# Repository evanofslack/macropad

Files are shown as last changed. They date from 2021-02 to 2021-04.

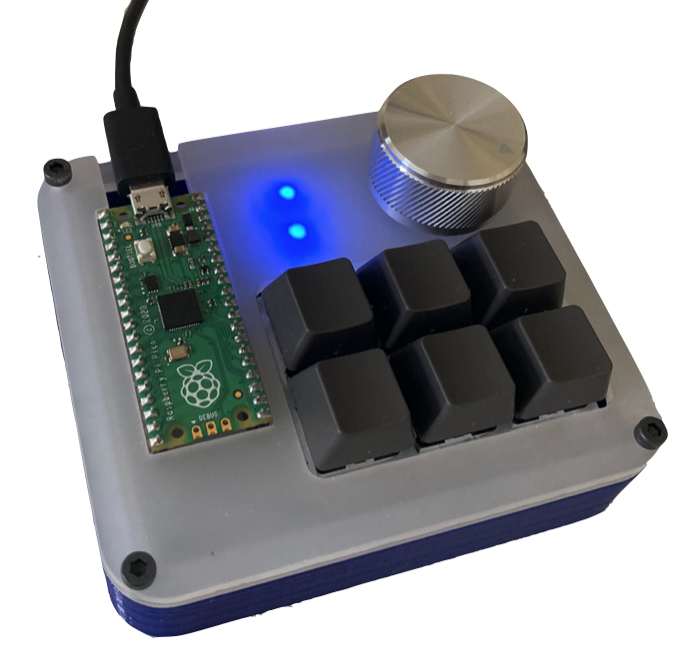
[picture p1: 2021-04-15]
Images/Final_Build.png

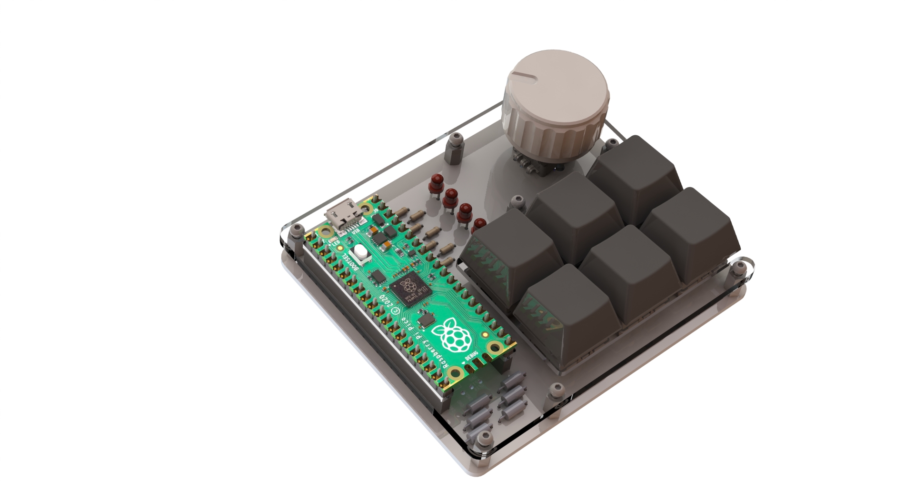
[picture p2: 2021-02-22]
Images/SlackPadv1.3 Render 1.JPG

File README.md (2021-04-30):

# MacroPad

Macropad utilizing the Raspberry Pi Pico. 3 layers of functionality, 6 switches, and 1 rotary encoder switch. Implements CircuitPython HID libraries and Adafruit matrix keypad library. Custom PCB designed in KiCAD (Gerbers can be found in the folder). Custom case designed in SolidWorks featuring a lasercut acrylic plates and a 3D printed base. 



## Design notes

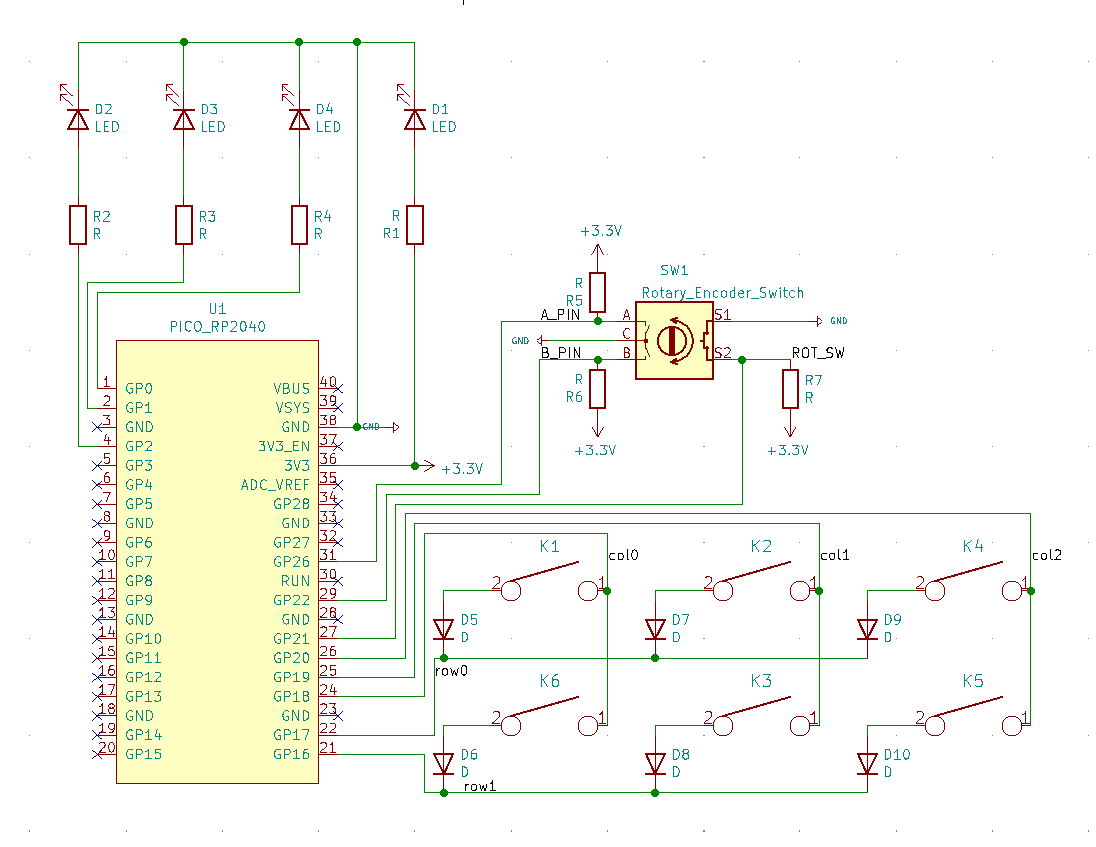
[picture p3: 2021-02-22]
Images/Schematic_v3.PNG

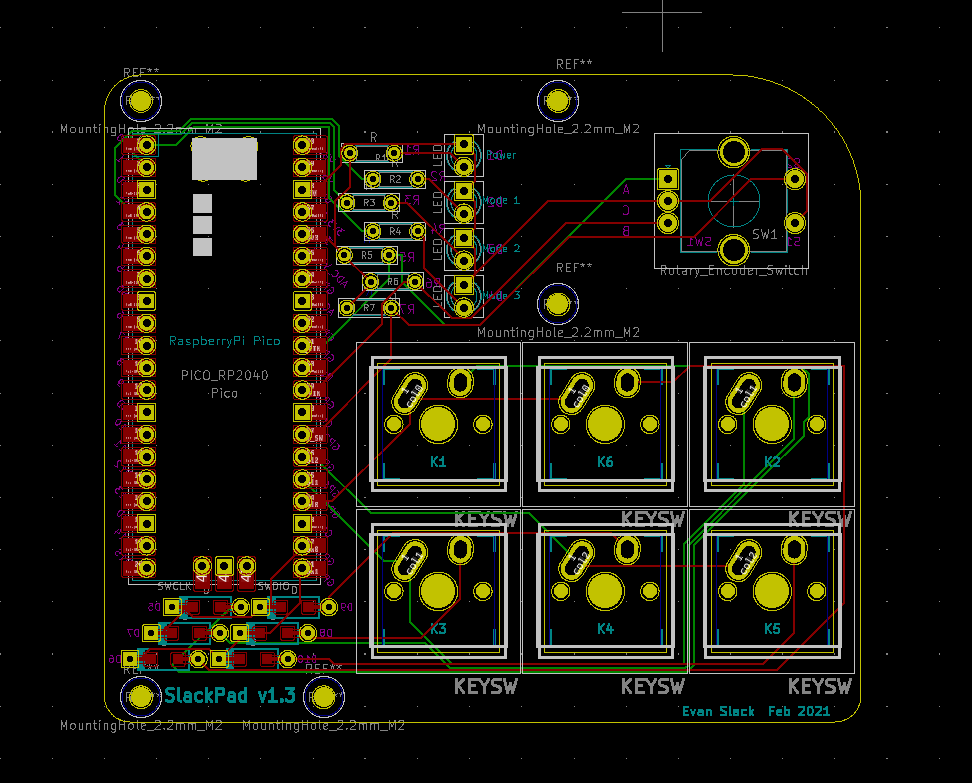
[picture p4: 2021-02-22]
Images/PCB_v3.PNG

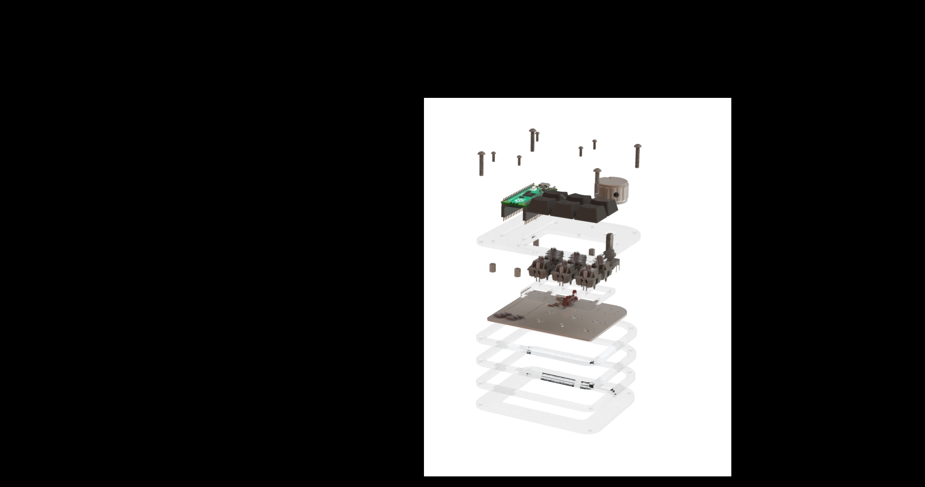
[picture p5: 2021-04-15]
Images/Untitled.JPG

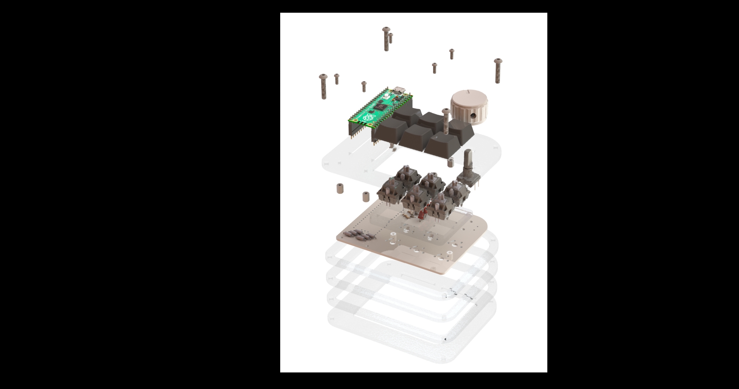
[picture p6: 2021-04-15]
Images/WEhite.JPG

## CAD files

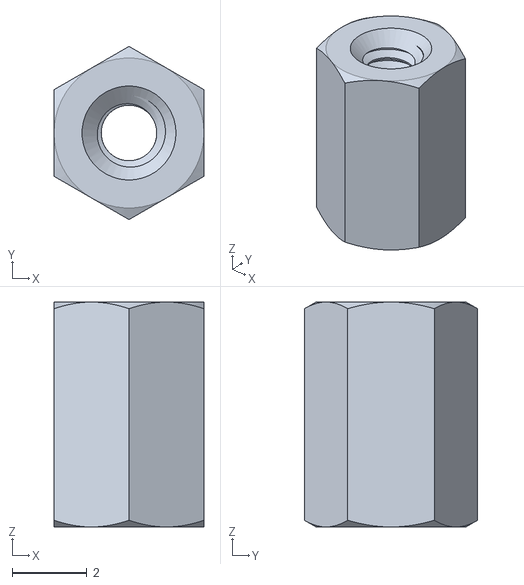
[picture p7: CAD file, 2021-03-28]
CAD/02_OTS/M2 Standoff.STL
4.00 x 4.62 x 6.00

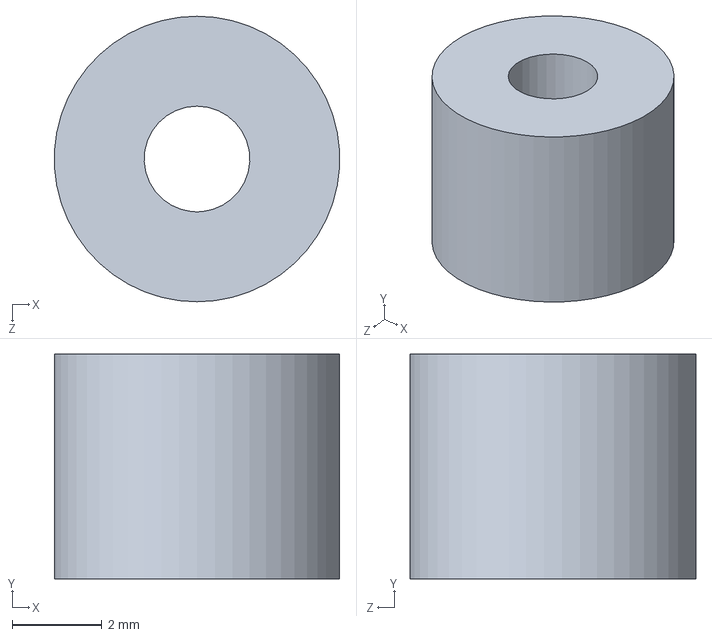
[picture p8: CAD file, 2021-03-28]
CAD/03_Acrylic/Custom Standoff.SLDPRT
6.34 x 5.00 x 6.35 mm

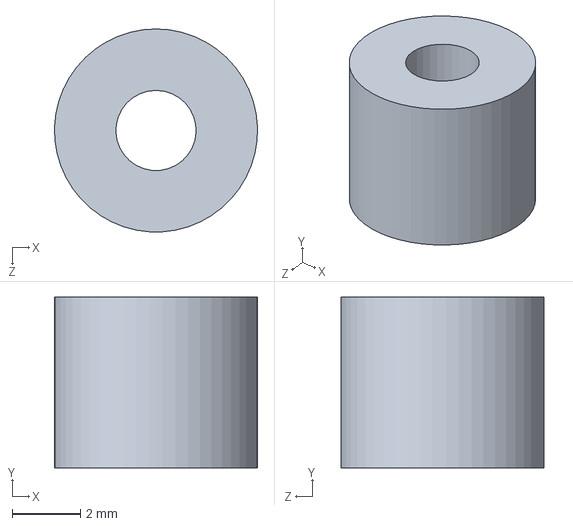
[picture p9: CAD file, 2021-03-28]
CAD/04_3DPrint/Custom Standoff.SLDPRT
5.95 x 5.00 x 5.95 mm

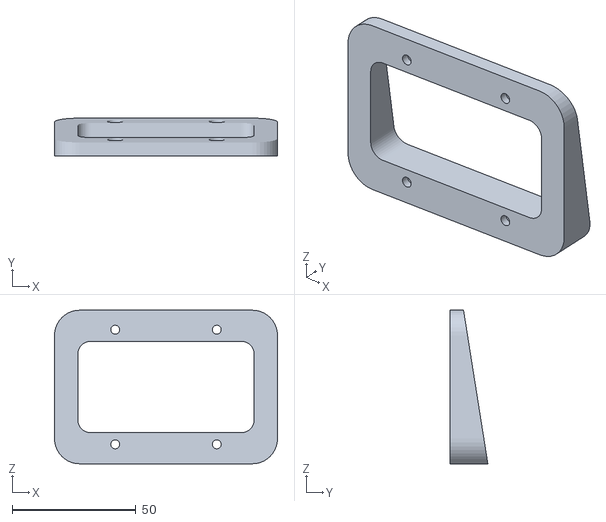
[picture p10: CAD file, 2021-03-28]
CAD/04_3DPrint/STL/Case Foot.STL
90.0 x 15.2 x 62.0

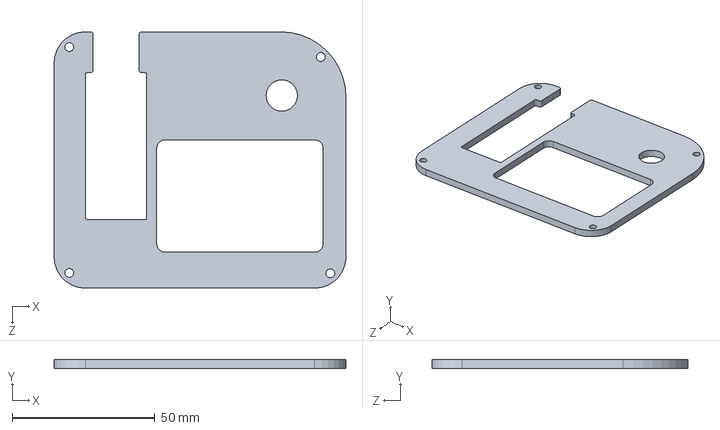
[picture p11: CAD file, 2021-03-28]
CAD/03_Acrylic/Acrylic Top Plate.SLDPRT
102.3 x 3.05 x 89.8 mm

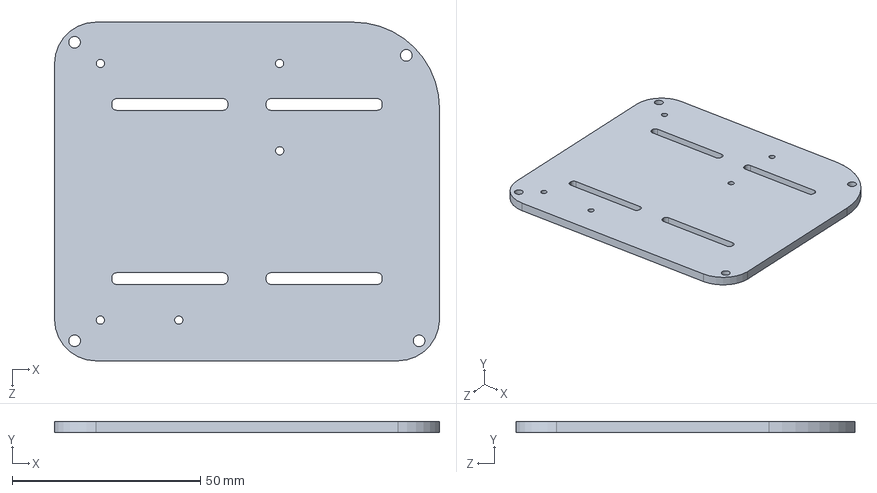
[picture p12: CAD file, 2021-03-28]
CAD/03_Acrylic/Bottom Case Plate NEW.SLDPRT
102.3 x 3.05 x 90.0 mm

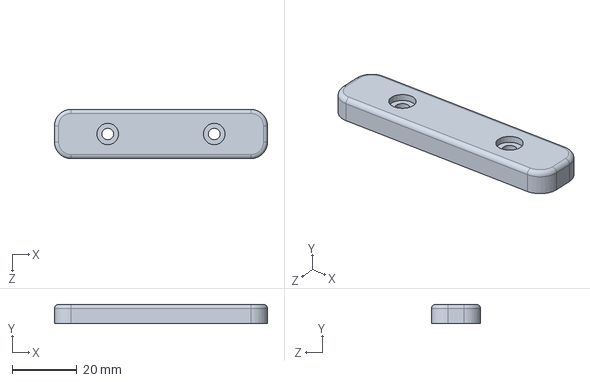
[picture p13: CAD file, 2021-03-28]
CAD/04_3DPrint/Case Foot Front.SLDPRT
66.0 x 6.00 x 15.2 mm

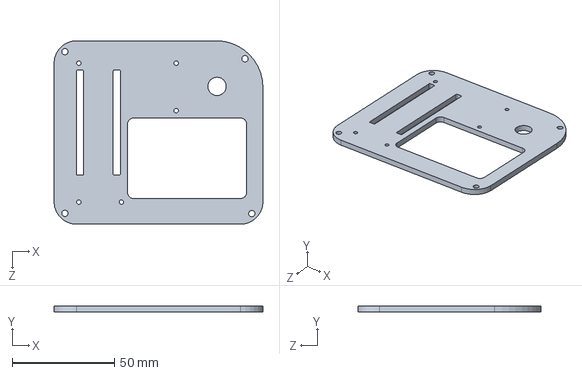
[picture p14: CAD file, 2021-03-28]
CAD/03_Acrylic/Top Case Plate.SLDPRT
102.3 x 3.05 x 89.8 mm

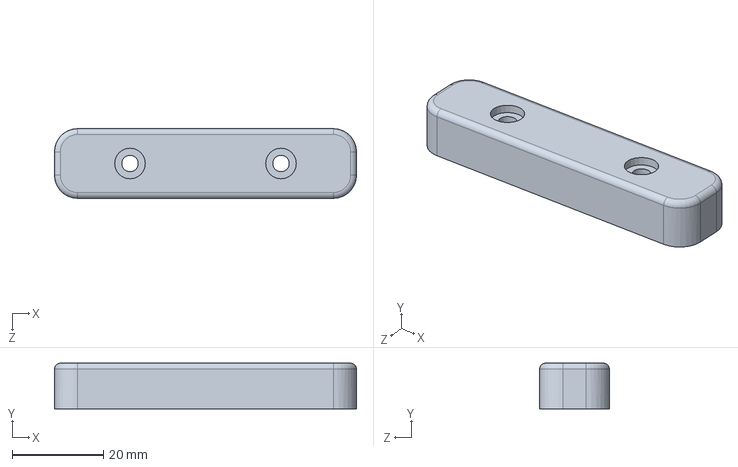
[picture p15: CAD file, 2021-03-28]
CAD/04_3DPrint/Case Foot Back.SLDPRT
66.0 x 10.0 x 15.2 mm

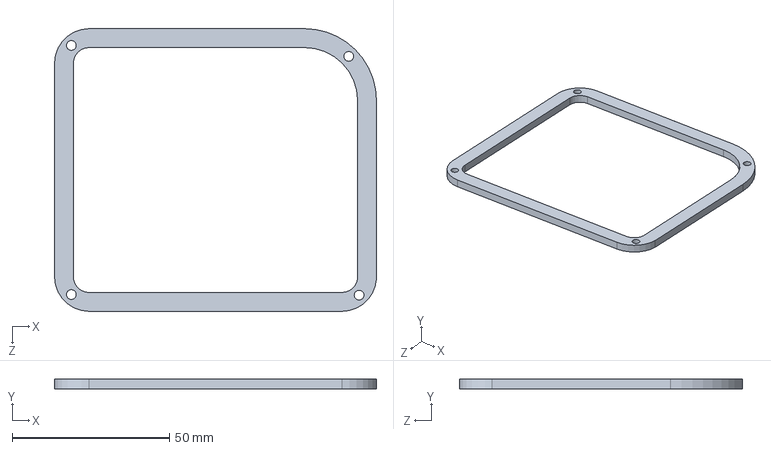
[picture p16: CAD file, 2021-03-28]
CAD/03_Acrylic/Middle Case Plate.SLDPRT
102.3 x 3.10 x 89.8 mm

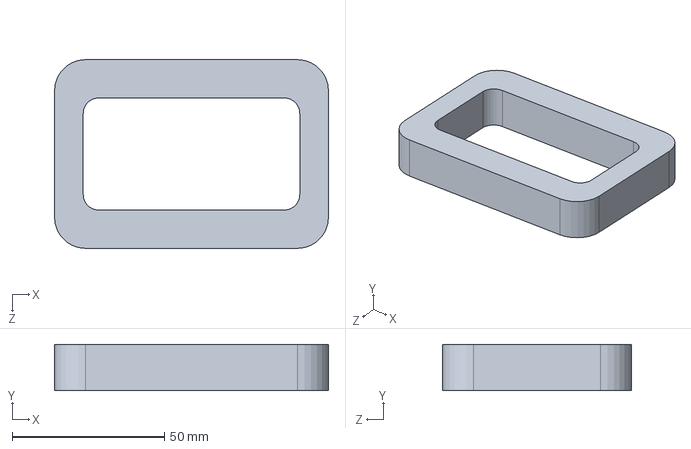
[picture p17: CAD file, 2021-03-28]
CAD/04_3DPrint/Case Base.SLDPRT
90.0 x 15.2 x 62.0 mm

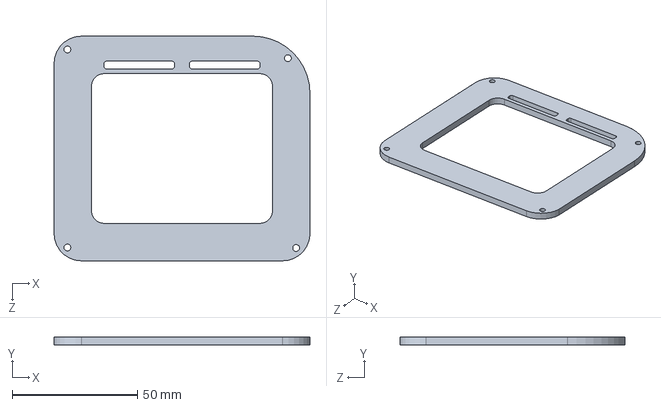
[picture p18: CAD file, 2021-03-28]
CAD/03_Acrylic/Bottom Case Plate.SLDPRT
102.3 x 3.10 x 89.8 mm

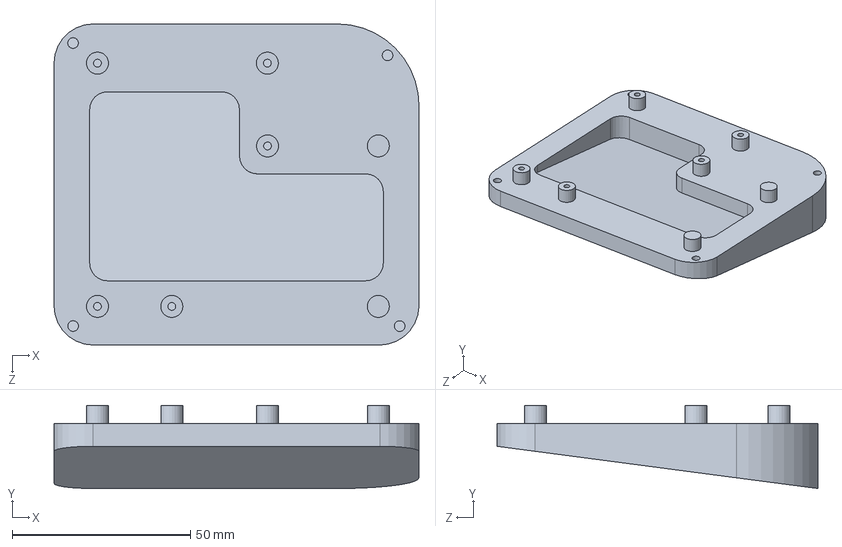
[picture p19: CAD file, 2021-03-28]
CAD/04_3DPrint/Case Bottom.SLDPRT
102.3 x 23.3 x 90.0 mm

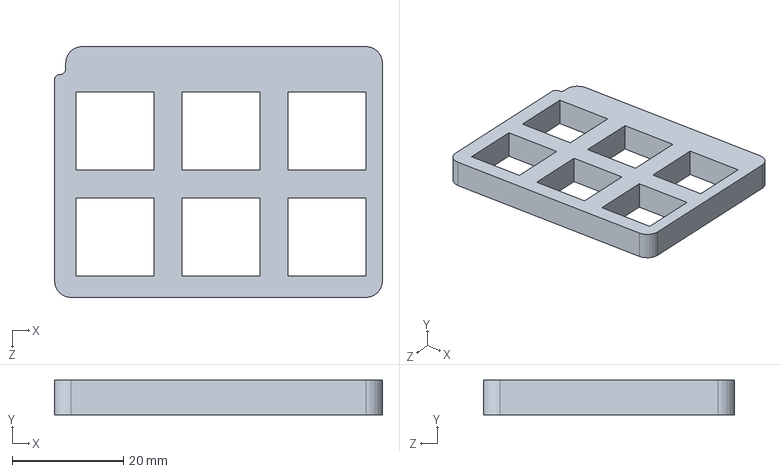
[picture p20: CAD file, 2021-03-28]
CAD/03_Acrylic/Keyswitch Plate.SLDPRT
58.9 x 6.20 x 45.0 mm

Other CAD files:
CAD/04_3DPrint/Case Foot Combined.SLDPRT
CAD/02_OTS/92095A184_BUTTON HEAD HEX DRIVE SCREW.SLDPRT
CAD/03_Acrylic/DXF/Acrylic Top Plate.DXF
CAD/03_Acrylic/DXF/Bottom Case Plate.DXF
CAD/03_Acrylic/DXF/Keyswitch Plate.DXF
CAD/03_Acrylic/DXF/Middle Case Plate.DXF
CAD/03_Acrylic/DXF/Top Case Plate.DXF
CAD/04_3DPrint/STL/Case Bottom.STL
CAD/04_3DPrint/STL/Custom Standoff.STL

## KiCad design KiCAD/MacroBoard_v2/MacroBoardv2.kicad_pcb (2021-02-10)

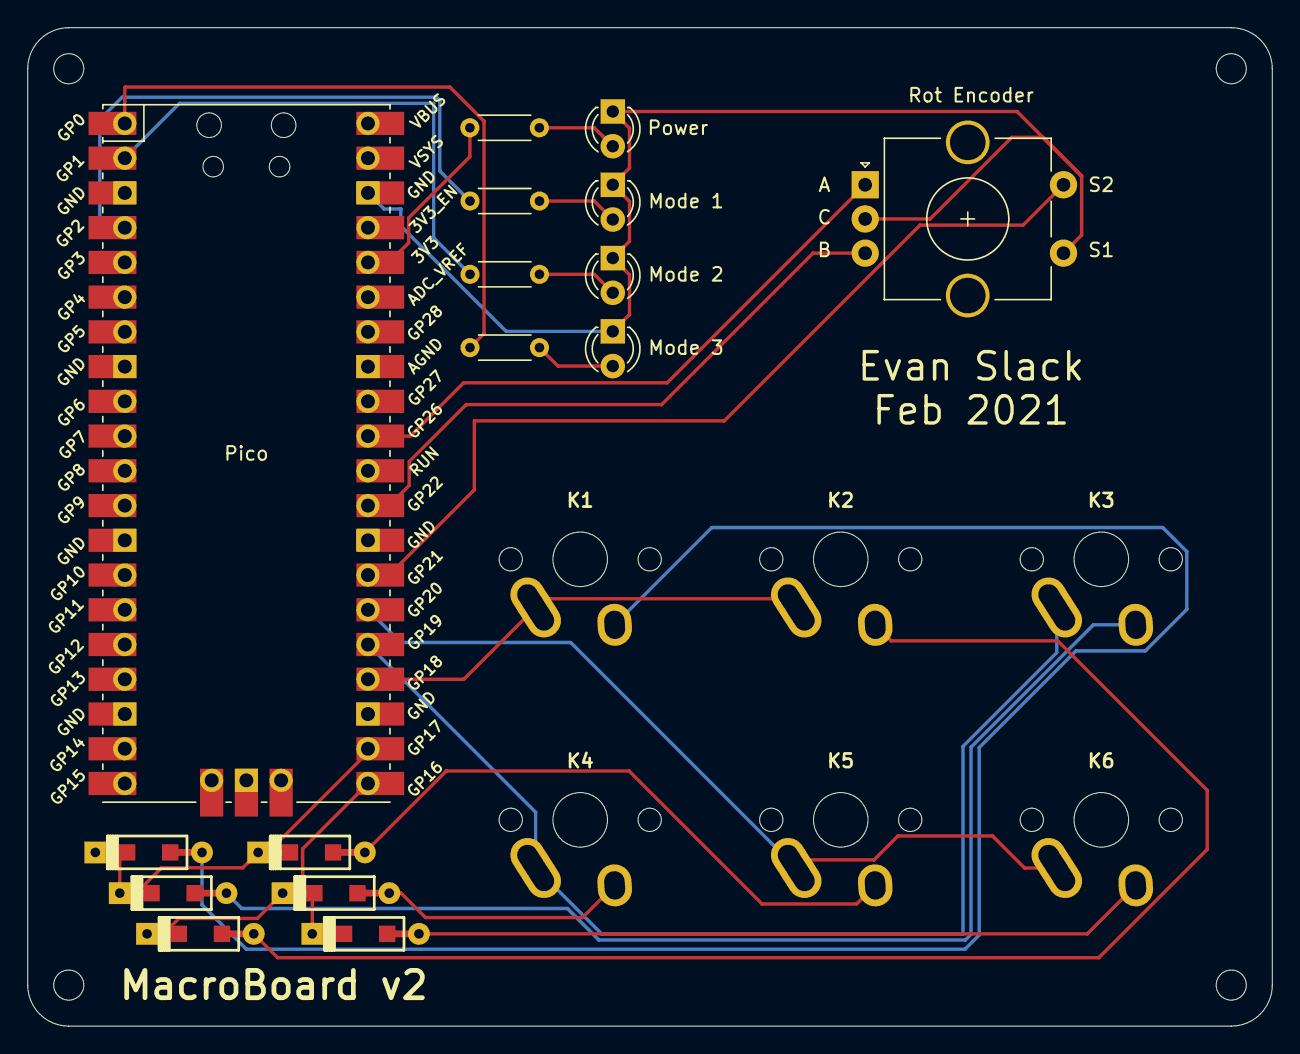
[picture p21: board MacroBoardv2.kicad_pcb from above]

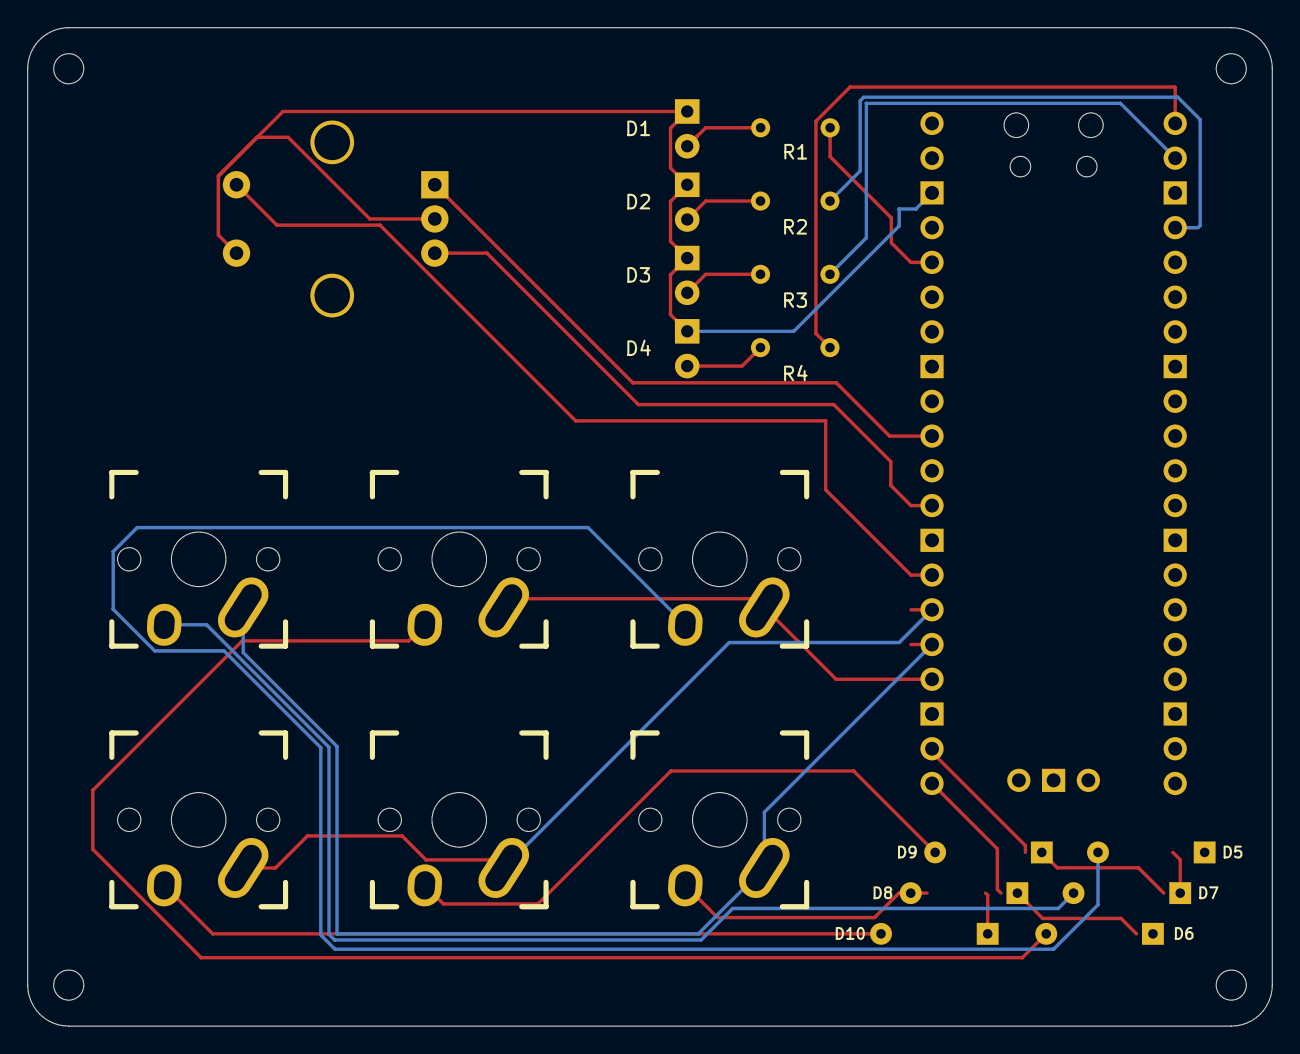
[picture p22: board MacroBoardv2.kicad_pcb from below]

Board: 2 copper layers, 91.0 x 73.0 mm, 22 parts (6 on the bottom side), 23 nets.

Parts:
D1, D2, D3, D4: LED; LED_D3.0mm
D5, D6, D7, D8, D9, D10: D; D_SOD123_axial
K1, K2, K3, K4, K5, K6: KEYSW; Mx_Alps_100
Pico: PICO_RP2040; RPi_Pico_SMD_TH
R1, R2, R3, R4: R; R_Axial_DIN0204_L3.6mm_D1.6mm_P5.08mm_Horizontal
Rot Encoder: Rotary_Encoder_Switch; RotaryEncoder_Alps_EC11E-Switch_Vertical_H20mm_CircularMoun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

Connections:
+5V: D1.1, D2.1, D3.1, D4.1, Pico.38, Rot Encoder.C, Rot Encoder.S1
/A_PIN: Pico.31, Rot Encoder.A
/B_PIN: Pico.29, Rot Encoder.B
/ROT_SW: Pico.27, Rot Encoder.S2
/col0: K1.1, K2.1, Pico.24
/col1: K3.1, K4.1, Pico.25
/col2: K5.1, K6.1, Pico.26
/row0: D5.1, D7.1, D9.1, Pico.22
unnamed: D1.2, R1.2
unnamed: D2.2, R2.1
unnamed: D3.2, R3.1
unnamed: D4.2, R4.1
unnamed: D5.2, K1.2
unnamed: D6.2, K2.2
unnamed: D7.2, K3.2
unnamed: D8.2, K4.2
unnamed: D9.2, K5.2
unnamed: D6.1, D8.1, D10.1, Pico.21
unnamed: D10.2, K6.2
unnamed: Pico.36, R1.1
unnamed: Pico.4, R2.2
unnamed: Pico.2, R3.2
unnamed: Pico.1, R4.2

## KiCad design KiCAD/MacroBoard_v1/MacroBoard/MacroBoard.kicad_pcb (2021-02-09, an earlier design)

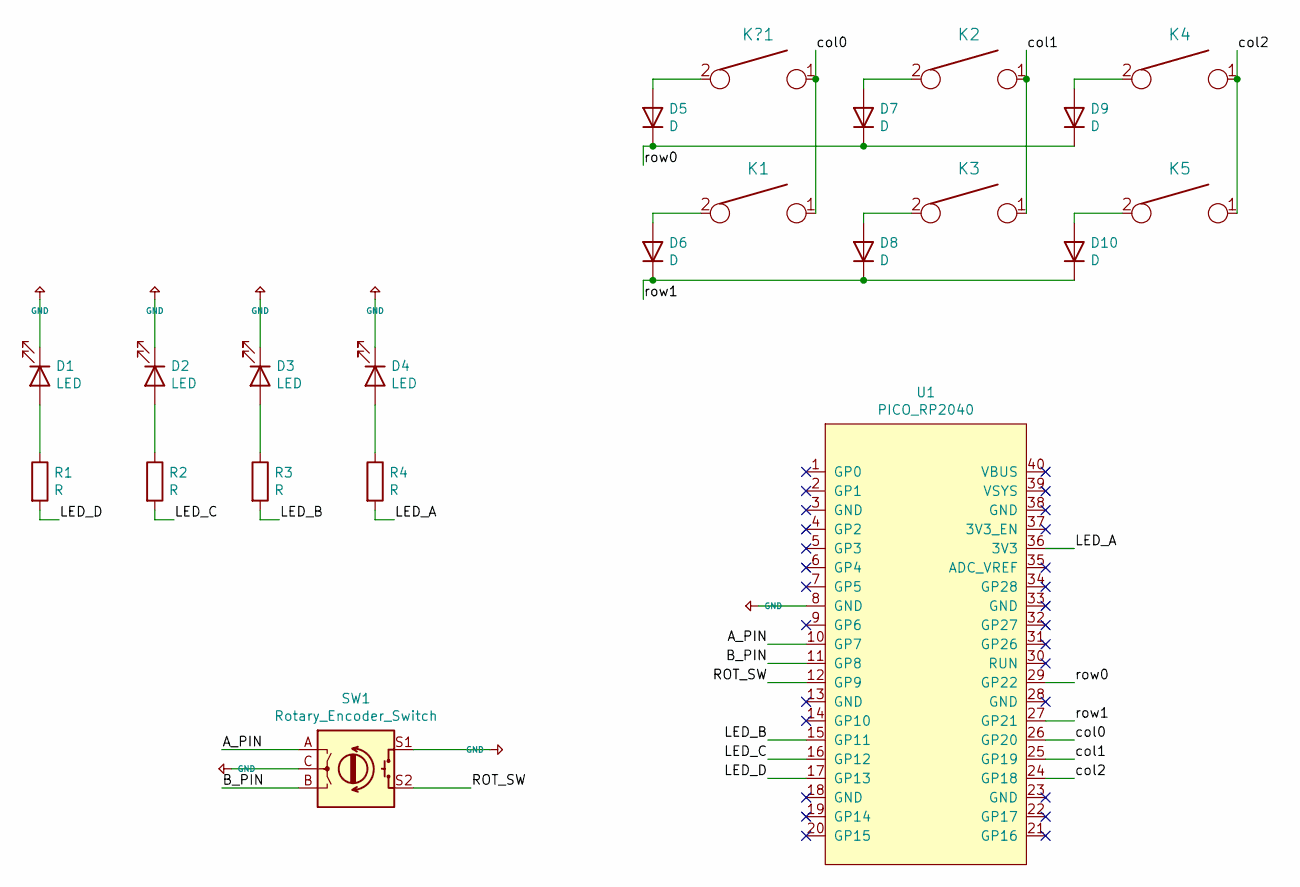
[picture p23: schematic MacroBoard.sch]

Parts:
D1, D2, D3, D4: LED; LED_D5.0mm
D5, D6, D7, D8, D9, D10: D; D_SOD123_axial
K1, K2, K3, K4, K5: KEYSW; Mx_Alps_100
K?1: KEYSW; Mx_Alps_100
R1, R2, R3, R4: R; R_Axial_DIN0204_L3.6mm_D1.6mm_P1.90mm_Vertical
SW1: Rotary_Encoder_Switch; RotaryEncoder_Alps_EC11E-Switch_Vertical_H20mm_CircularMoun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
U1: PICO_RP2040; RPi_Pico_SMD_TH

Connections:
+5V: D1.1 (K), D2.1 (K), D3.1 (K), D4.1 (K), SW1.C, SW1.S1, U1.8 (GND)
/A_PIN: SW1.A, U1.10 (GP7)
/B_PIN: SW1.B, U1.11 (GP8)
/LED_A: R4.2, U1.36 (3V3)
/LED_B: R3.2, U1.15 (GP11)
/LED_C: R2.2, U1.16 (GP12)
/LED_D: R1.2, U1.17 (GP13)
/ROT_SW: SW1.S2, U1.12 (GP9)
/col0: K1.1, K?1.1, U1.26 (GP20)
/col1: K2.1, K3.1, U1.25 (GP19)
/col2: K4.1, K5.1, U1.24 (GP18)
/row0: D5.1 (K), D7.1 (K), D9.1 (K), U1.29 (GP22)
/row1: D6.1 (K), D8.1 (K), D10.1 (K), U1.27 (GP21)
unnamed: D1.2 (A), R1.1
unnamed: D2.2 (A), R2.1
unnamed: D3.2 (A), R3.1
unnamed: D4.2 (A), R4.1
unnamed: D5.2 (A), K?1.2
unnamed: D6.2 (A), K1.2
unnamed: D7.2 (A), K2.2
unnamed: D8.2 (A), K3.2
unnamed: D9.2 (A), K4.2
unnamed: D10.2 (A), K5.2

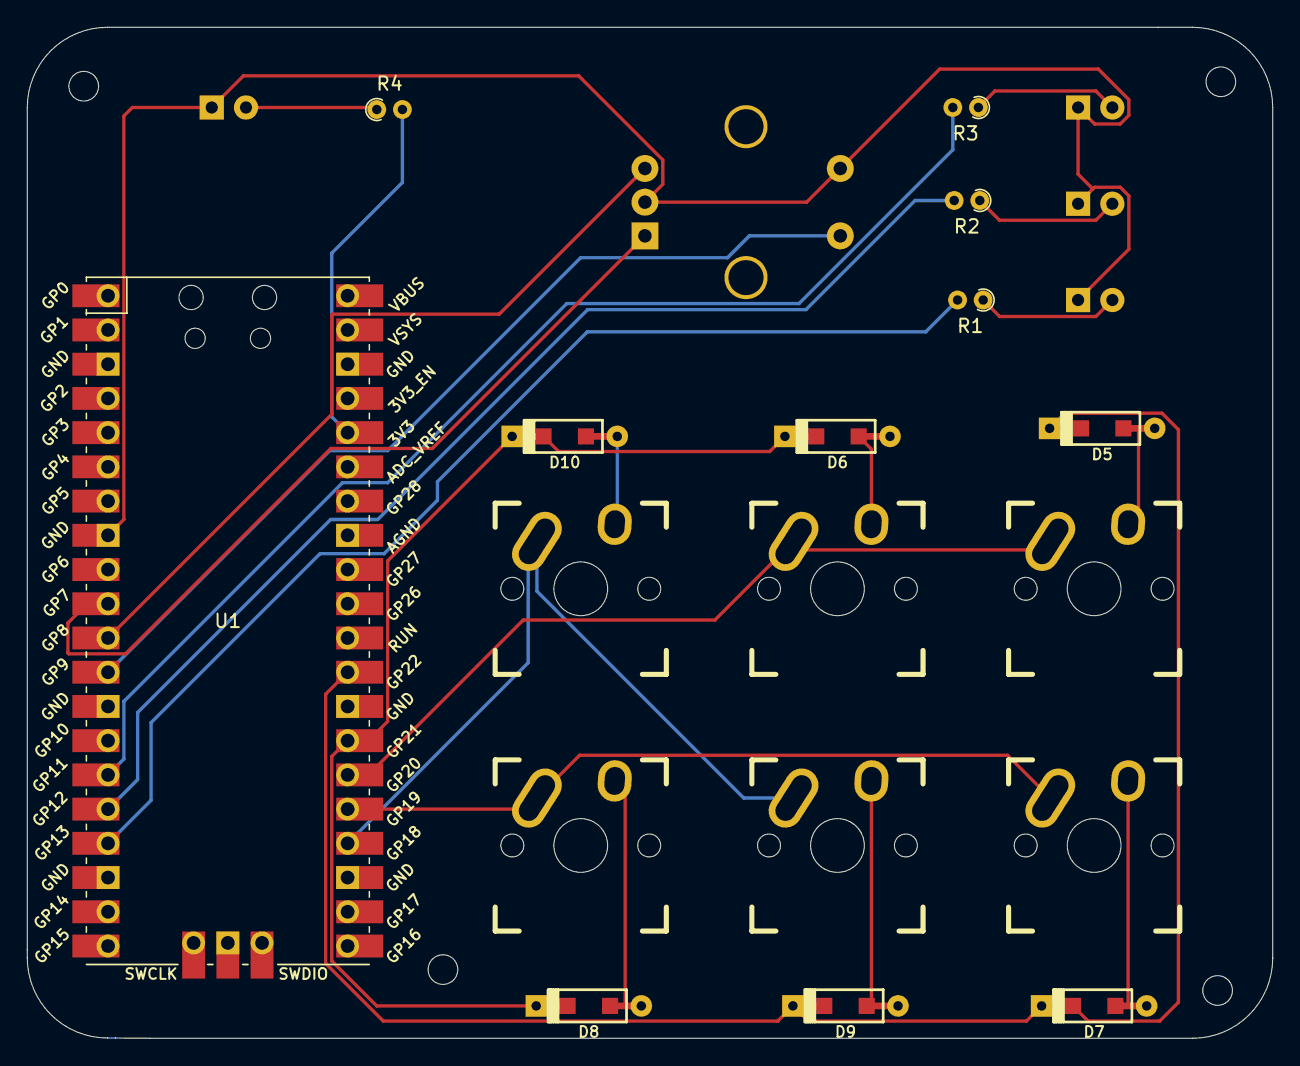
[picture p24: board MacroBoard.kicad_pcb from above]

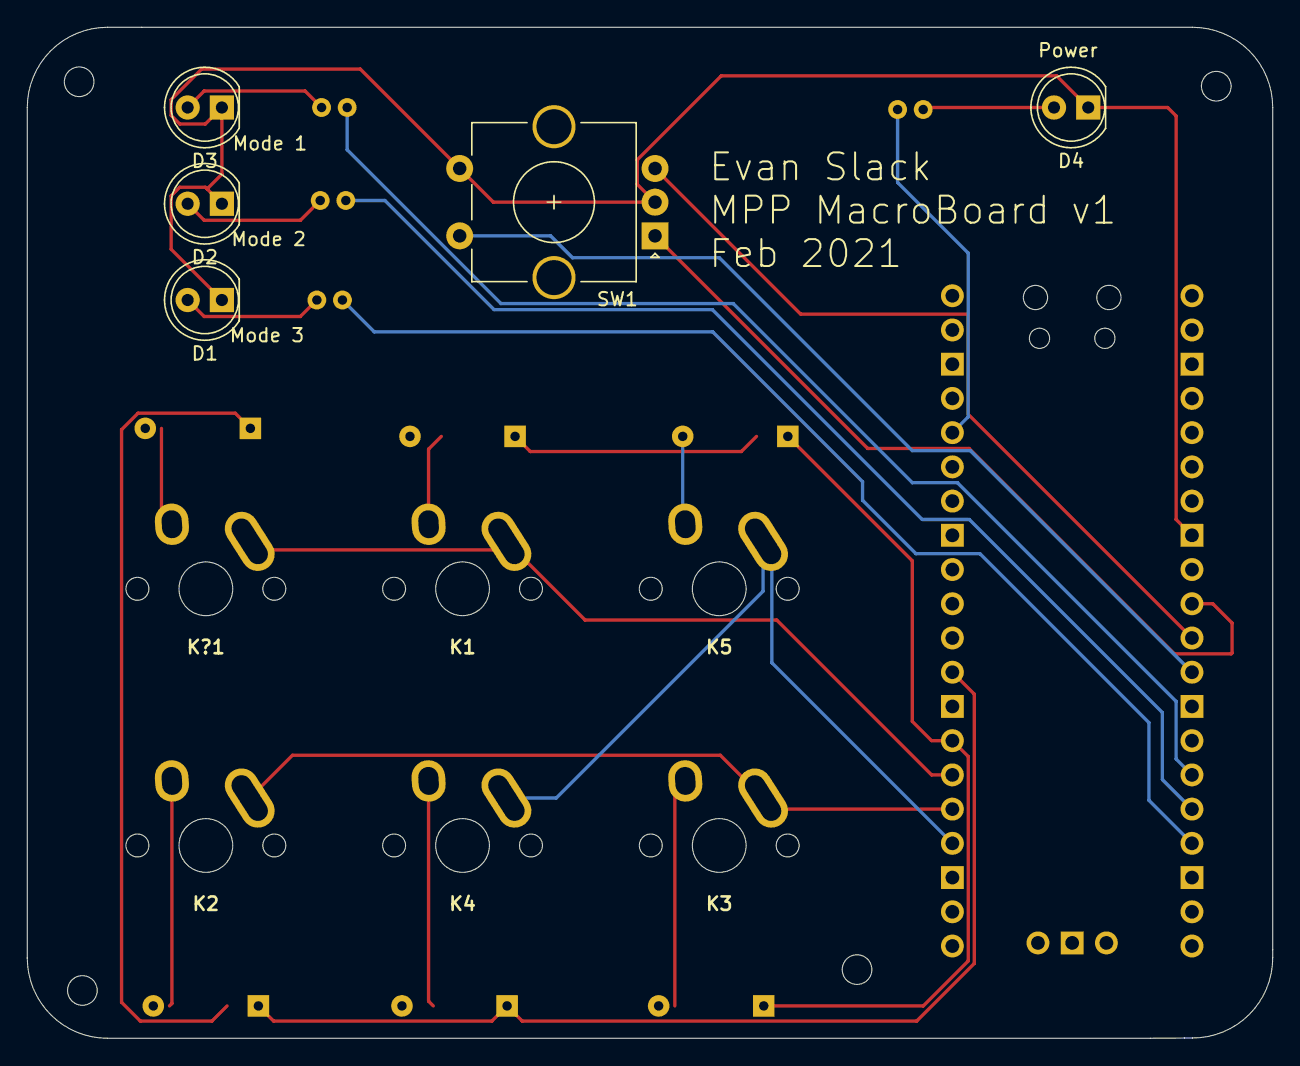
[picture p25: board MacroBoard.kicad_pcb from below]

Board: 2 copper layers, 92.4 x 75.0 mm, 26 parts (5 on the bottom side), 23 nets.

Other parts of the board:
 : MountingHole_2.2mm_M2
  : MountingHole_2.2mm_M2
 #2,  #3: MountingHole_2.2mm_M2

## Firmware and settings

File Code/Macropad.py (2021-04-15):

# Macropad Shortcuts Code 
# Evan Slack
# Written with circuitpython

import time
import digitalio
import board
import adafruit_matrixkeypad
import usb_hid

from adafruit_hid.keyboard import Keyboard
from adafruit_hid.keycode import Keycode

from adafruit_hid.consumer_control import ConsumerControl
from adafruit_hid.consumer_control_code import ConsumerControlCode

# Set up a keyboard device.
kbd = Keyboard(usb_hid.devices)

# Set up consumer control
cc = ConsumerControl(usb_hid.devices)

# Define LEDs
led1 = digitalio.DigitalInOut(board.GP2)
led1.direction = digitalio.Direction.OUTPUT
led2 = digitalio.DigitalInOut(board.GP1)
led2.direction = digitalio.Direction.OUTPUT
led3 = digitalio.DigitalInOut(board.GP0)
led3.direction = digitalio.Direction.OUTPUT

# Define Encoder switch
button = digitalio.DigitalInOut(board.GP21)
button.switch_to_input(pull=digitalio.Pull.UP)

# Define switch matrix
cols = [digitalio.DigitalInOut(x) for x in (board.GP18, board.GP19, board.GP20)]
rows = [digitalio.DigitalInOut(x) for x in (board.GP17, board.GP16)]
keys = ((1, 3, 5),
        (2, 4, 6))

# Define key presses    
keypad = adafruit_matrixkeypad.Matrix_Keypad(rows, cols, keys)

# Define layer
layer = 1

# Convert key presses to executable shortcuts
while True:
    
    if button.value == False:
        layer = layer + 1
        if layer == 4:
            layer = 1
    #print (layer)
        
    
    time.sleep(.15) 
        
    
    keys = keypad.pressed_keys

    # Set media layer
    if layer == 1:
        
        led1.value = True
        led3.value = False
        
        if keys == [1]:
            # Go back to previous track
            cc.send(ConsumerControlCode.SCAN_PREVIOUS_TRACK)
            
        elif keys == [2]:
            # Play/Pause
            cc.send(ConsumerControlCode.PLAY_PAUSE)
            
        elif keys == [3]:
            # Skip to next track
            cc.send(ConsumerControlCode.SCAN_NEXT_TRACK)
            
        elif keys == [4]:
            # Window Navigator
            kbd.send(Keycode.F12)    
            
        elif keys == [5]:
            # Lower Volume
            cc.send(ConsumerControlCode.VOLUME_DECREMENT)
        
        elif keys == [6]:
            # Raise volume
            cc.send(ConsumerControlCode.VOLUME_INCREMENT)
            
            
        
    # Set Zoom Layer
    if layer == 2:
        
        led2.value = True
        led1.value = False
        
        
        if keys == [1]:
            # Mute Mic Zoom
            kbd.send(Keycode.F13)
            
        elif keys == [2]:
            # Toggle camera
            kbd.send(Keycode.GUI, Keycode.B)
            
        elif keys == [3]:
            # Switch gallery to speaker view
            kbd.send(Keycode.SHIFT, Keycode.GUI, Keycode.W)
            
        elif keys == [4]:
            # Window Navigator
            kbd.send(Keycode.F12)
            
        elif keys == [5]:
            # Show Chat
            kbd.send(Keycode.SHIFT, Keycode.GUI, Keycode.H) 
            
        elif keys == [6]:
            # End meeting
            kbd.send(Keycode.GUI, Keycode.W)
    
    if layer == 3:
        
        led3.value = True
        led2.value = False
        
        
        
    #time.sleep(0.1)
    

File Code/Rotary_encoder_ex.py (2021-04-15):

import rotaryio
import board
import digitalio
import usb_hid
from adafruit_hid.consumer_control import ConsumerControl
from adafruit_hid.consumer_control_code import ConsumerControlCode
 
button = digitalio.DigitalInOut(board.D12)
button.direction = digitalio.Direction.INPUT
button.pull = digitalio.Pull.UP
 
cc = ConsumerControl(usb_hid.devices)
 
button_state = None
last_position = encoder.position


encoder = rotaryio.IncrementalEncoder(board.GP26, board.GP22)
 
while True:
    current_position = encoder.position
    position_change = current_position - last_position
    if position_change > 0:
        for _ in range(position_change):
            cc.send(ConsumerControlCode.VOLUME_INCREMENT)
        print(current_position)
    elif position_change < 0:
        for _ in range(-position_change):
            cc.send(ConsumerControlCode.VOLUME_DECREMENT)
        print(current_position)
    last_position = current_position
    
    
    if not button.value and button_state is None:
        button_state = "pressed"
    if button.value and button_state == "pressed":
        print("Button pressed.")
        cc.send(ConsumerControlCode.PLAY_PAUSE)
        button_state = None

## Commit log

2021-02-09 Added KiCAD files
    [MacroBoard-B_Cu.gbl, MacroBoard-B_Mask.gbs, MacroBoard-B_Paste.gbp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]
2021-02-10 Updated Schematic and PCB for revision 2
    [MacroBoard-B_Cu.gbl, MacroBoard-B_Mask.gbs, MacroBoard-B_Paste.gbp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]
2021-02-22 Added SolidWorks Models
    [1x10 Female Header.SLDASM, 1x10 TH Vert 100mil.SLDPRT, 1x10 TH Vert 100mil.step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]
2021-03-28 Added initial Circuitpython code
2021-03-28 Updated Assembly
    New stacked acrylic housing and new 3D printed base
    [1x10 Female Header.SLDASM, 1x10 TH Vert 100mil.SLDPRT, 1x10 TH Vert 100mil.step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]
2021-03-28 Messed up the commit
    [1x10 Female Header.SLDASM, 1x10 TH Vert 100mil.SLDPRT, 1x10 TH Vert 100mil.step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]
2021-03-28 Updated Assembly
    Updated stacked acrylic case and made new 3D printed base
    [92095A184_BUTTON HEAD HEX DRIVE SCREW.SLDPRT, Acrylic Top Plate.DXF, Acrylic Top Plate.SLDPRT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]
2021-04-15 Added Rotary Encoder Example
